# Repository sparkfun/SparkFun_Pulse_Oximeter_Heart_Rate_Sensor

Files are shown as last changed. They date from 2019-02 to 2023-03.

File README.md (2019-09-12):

SparkFun Pulse Oximeter and Heart Rate Monitor 
========================================

SparkFun Pulse Oximeter and Heart Rate Monitor

[*SparkFun Pulse Oximeter and Heart Rate Monitor (SEN-15291)*](https://www.sparkfun.com/products/15219)

The SparkFun Pulse Oximeter and Heart-Rate Sensor is an I&sup2;C based [biometric](https://en.wikipedia.org/wiki/Biometrics) sensor, utilizing two chips from Maxim Integrated: 
the MAX32664 Bio Metric Sensor Hub and the MAX30101 Pulse Oximetry and Heart-Rate Module.

The MAX30101 does all the sensing by utilizing its' internal LEDs to bounce light off the arteries and arterioles in your finger's subcutaneous layer and sensing how much light 
is absorbed with its' photodetectors . This is known as [photoplethysmography](https://en.wikipedia.org/wiki/Photoplethysmogram). This data is passed onto and analyzed by the 
MAX32664 which applies its' algorithms to determine heart rate and blood oxygen saturation (SpO2). The embedded algorithm uses digital filtering, pressure/position compensation, 
advanced R-wave detection and automatic gain control to determine the heart rate in beats per minute while minimizing power.  SpO2 results are reported as percentage of hemoglobin 
that is saturated with oxygen. It also provides useful information such as the sensor's confidence in its' reportings as well as a handy finger detection data point. To get the 
most out of the sensor we've written an Arduino Library to make it easy to adjust all the possible configurations.

Repository Contents
-------------------

* **/Documentation** - Data sheets and additional product information.
* **/Firmware** - Programming File for the MAX32664 
* **/Hardware** - Eagle design files (.brd, .sch)
* **/Production** - Production panel files (.brd)

Documentation
--------------
* **[Arduino Library](https://github.com/sparkfun/SparkFun_Bio_Sensor_Hub_Library)** - Arduino Library with Example Sketches
* **[Hookup Guide](https://learn.sparkfun.com/tutorials/sparkfun-pulse-oximeter-and-heart-rate-monitor-hookup-guide)** - Basic hookup guide for the SparkFun Pulse Oximeter and Heart Rate Sensor.

Product Versions
----------------
* [SEN-15291](https://www.sparkfun.com/products/15219)- SparkFun Version 1.0

License Information
-------------------

This product is _**open source**_! 

Please review the LICENSE.md file for license information. 

If you have any questions or concerns on licensing, please contact technical support on our [SparkFun forums](https://forum.sparkfun.com/viewforum.php?f=152).

Distributed as-is; no warranty is given.

- Your friends at SparkFun.

_<COLLABORATION CREDIT>_

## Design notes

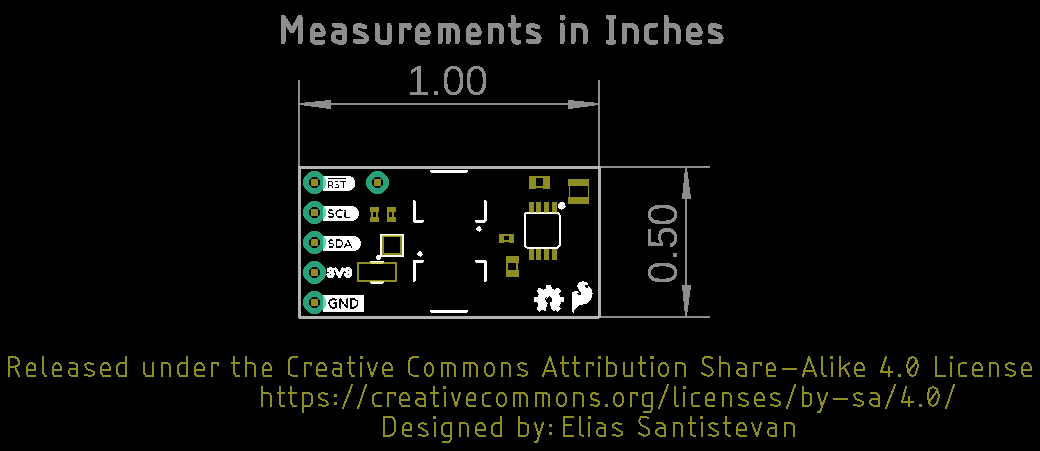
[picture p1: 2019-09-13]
Documentation/SparkFun_Pulse_Oximeter_Heart_Rate_Sensor_Dimensions.png

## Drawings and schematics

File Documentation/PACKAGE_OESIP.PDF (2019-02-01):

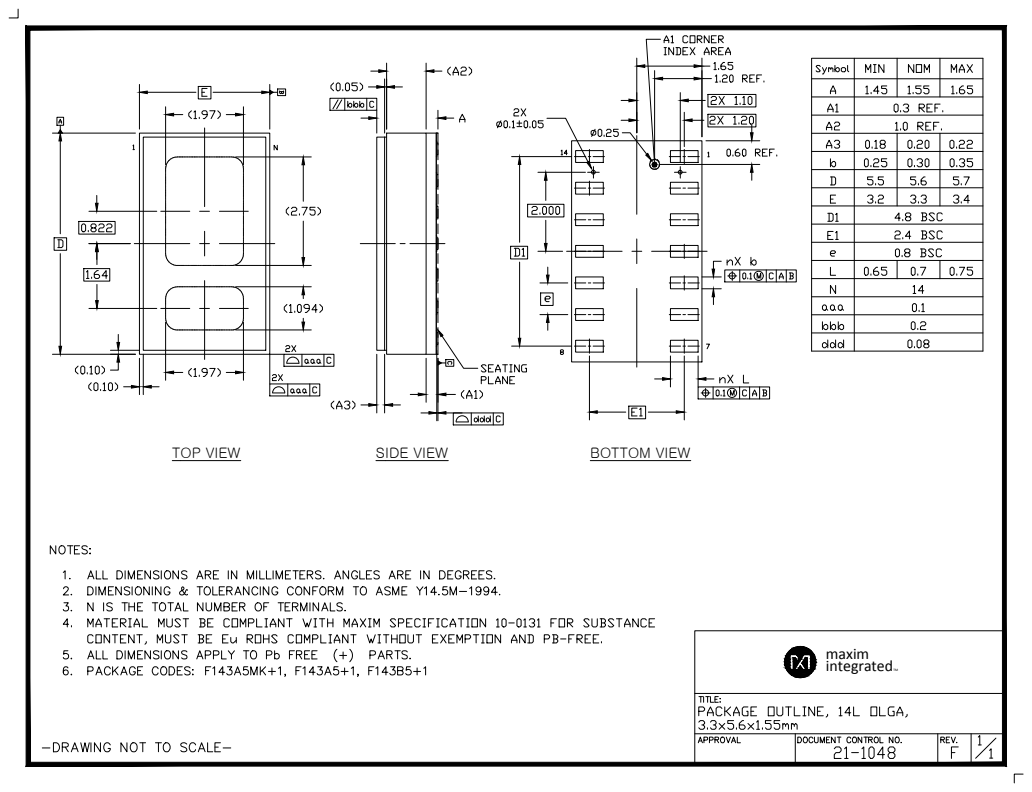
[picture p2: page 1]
maxim integratedTM TOP VIEW; SIDE VIEW; BOTTOM VIEW

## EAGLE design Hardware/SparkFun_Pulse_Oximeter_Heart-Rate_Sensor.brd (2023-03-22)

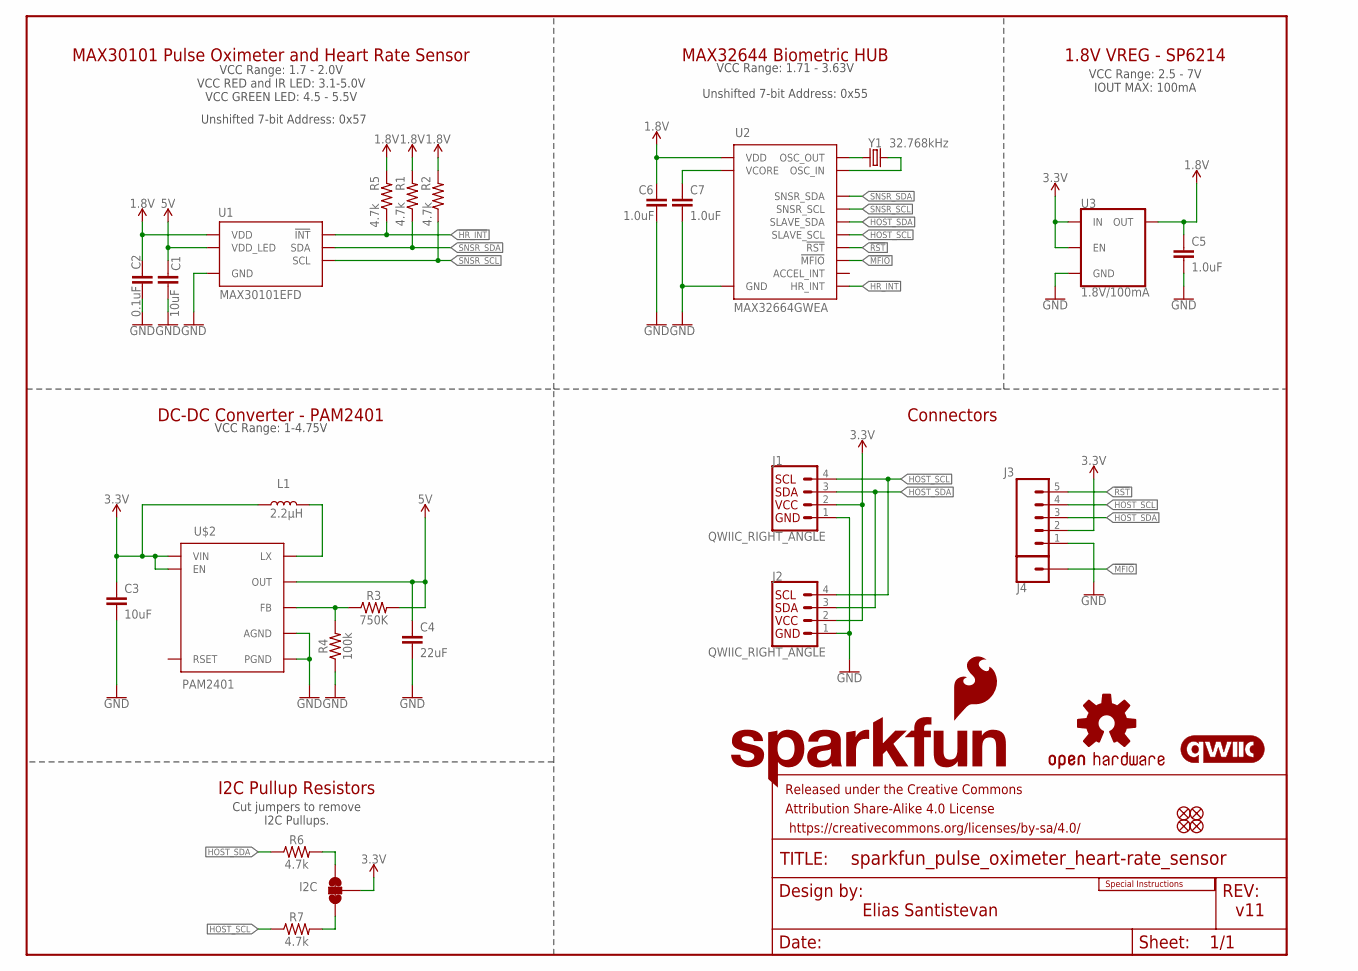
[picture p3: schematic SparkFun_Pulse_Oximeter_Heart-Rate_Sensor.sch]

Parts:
C1, C3: 10uF; 0603
C2: 0.1uF; 0402-TIGHT
C4: 22uF; 0805
C5: 1.0uF; 0603
C6, C7: 1.0uF; 0402-TIGHT
FD1, FD2, FD3, FD4: FIDUCIALUFIDUCIAL; FIDUCIAL-MICRO
FRAME1: FRAME-LETTER; CREATIVE_COMMONS
I2C: JUMPER-SMT_3_2-NC_TRACE_SILK; SMT-JUMPER_3_2-NC_TRACE_SILK
J1, J2: QWIIC_RIGHT_ANGLE; JST04_1MM_RA
J3: CONN_05NO_SILK; 1X05_NO_SILK
J4: CONN_01PTH_NO_SILK_YES_STOP; 1X01_NO_SILK
L1: 2.2μH; 0806
LOGO1: SFE_LOGO_FLAME.1_INCH; SFE_LOGO_FLAME_.1
LOGO2: OSHW-LOGOMINI; OSHW-LOGO-MINI
LOGO3: SFE_LOGO_NAME.1_INCH; SFE_LOGO_NAME_.1
LOGO4: SPECIAL_INSTRUCTIONS-ORDERING; ORDERING_INSTRUCTIONS
LOGO5: QWIIC_LOGO_4MM; QWIIC_4MM
R1, R2, R5, R6, R7: 4.7k; 0603
R3: 750K; 0603
R4: 100k; 0402-TIGHT
U1: MAX30101EFD; 14_PIN_OESIP
U2: MAX32664GWEA; 16_PIN_WLP
U3: 1.8V/100mA; SC70
U$2: PAM2401; MSOP8
Y1: 32.768kHz; CRYSTAL-SMD-3.2X1.5MM

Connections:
1.8V: C2.1, C5.1, C6.1, R1.2, R2.2, R5.2, U1.P11 (VDD), U2.3 (VDD), U3.5 (OUT)
3.3V: C3.1, I2C.2, J1.2, J2.2, J3.2, L1.1, U3.1 (IN), U3.3 (EN), U$2.2 (EN), U$2.3 (VIN)
5V: C1.1, C4.1, R3.2, U1.P9 (VDD_LED), U1.P10 (VDD_LED), U$2.7 (OUT)
!HR_INT: R5.1, U1.P13 (!INT), U2.6 (HR_INT)
!MFIO: J4.1, U2.16 (!MFIO)
!RST: J3.5, U2.12 (!RST)
GND: C1.2, C2.2, C3.2, C4.2, C5.2, C6.2, C7.2, J1.1, J2.1, J3.1, R4.1, U1.P4 (GND), U1.P12 (GND), U2.13 (GND), U3.2 (GND), U$2.4 (AGND), U$2.8 (PGND)
HOST_SCL: J1.4, J2.4, J3.4, R7.1, U2.10 (SLAVE_SCL)
HOST_SDA: J1.3, J2.3, J3.3, R6.1, U2.9 (SLAVE_SDA)
unnamed: C7.1, U2.4 (VCORE)
unnamed: R3.1, R4.2, U$2.5 (FB)
unnamed: L1.2, U$2.1 (LX)
unnamed: I2C.3, R6.2
unnamed: I2C.1, R7.2
unnamed: U2.1 (OSC_OUT), Y1.P$1 (1)
unnamed: U2.2 (OSC_IN), Y1.P$2 (2)
SNSR_SCL: R2.1, U1.P2 (SCL), U2.5 (SNSR_SCL)
SNSR_SDA: R1.1, U1.P3 (SDA), U2.14 (SNSR_SDA)

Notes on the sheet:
Elias Santistevan
v11
VCC Range: 1.71 - 3.63V
Unshifted 7-bit Address: 0x55
MAX30101 Pulse Oximeter and Heart Rate Sensor
MAX32644 Biometric HUB
1.8V VREG - SP6214
DC-DC Converter - PAM2401
Connectors
I2C Pullup Resistors
VCC Range: 1.7 - 2.0V VCC RED and IR LED: 3.1-5.0V VCC GREEN LED: 4.5 - 5.5V
Unshifted 7-bit Address: 0x57
VCC Range: 2.5 - 7V IOUT MAX: 100mA
VCC Range: 1-4.75V
Cut jumpers to remove I2C Pullups.

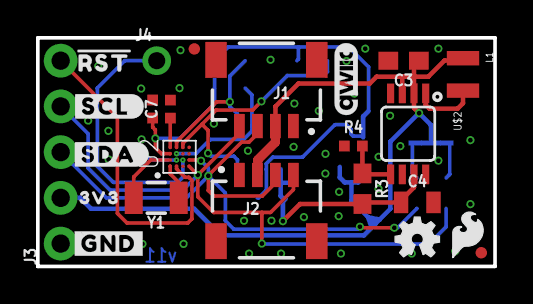
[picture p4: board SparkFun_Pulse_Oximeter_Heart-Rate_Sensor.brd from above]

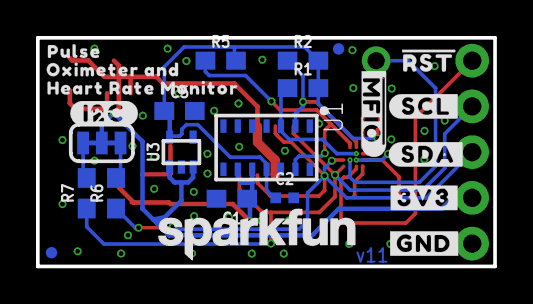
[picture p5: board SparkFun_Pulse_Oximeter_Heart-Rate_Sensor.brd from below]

Board: 2 copper layers, 25.4 x 12.7 mm, 50 parts (24 on the bottom side), 18 nets.

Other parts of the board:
U$1: #I2C#1348
U$3, U$5: #GND#0
U$4: #SCL#7
U$6, U$12: #RST#32
U$7: 3V338
U$8: #SDA#10
U$9: #3V3#1
U$10: #SDA#9
U$11: #SCL#9
U$13: ##MFIO##12
U$17: PULSE35
U$20: OXIMETER_AND36
U$21: HEART_RATE_MONITOR37

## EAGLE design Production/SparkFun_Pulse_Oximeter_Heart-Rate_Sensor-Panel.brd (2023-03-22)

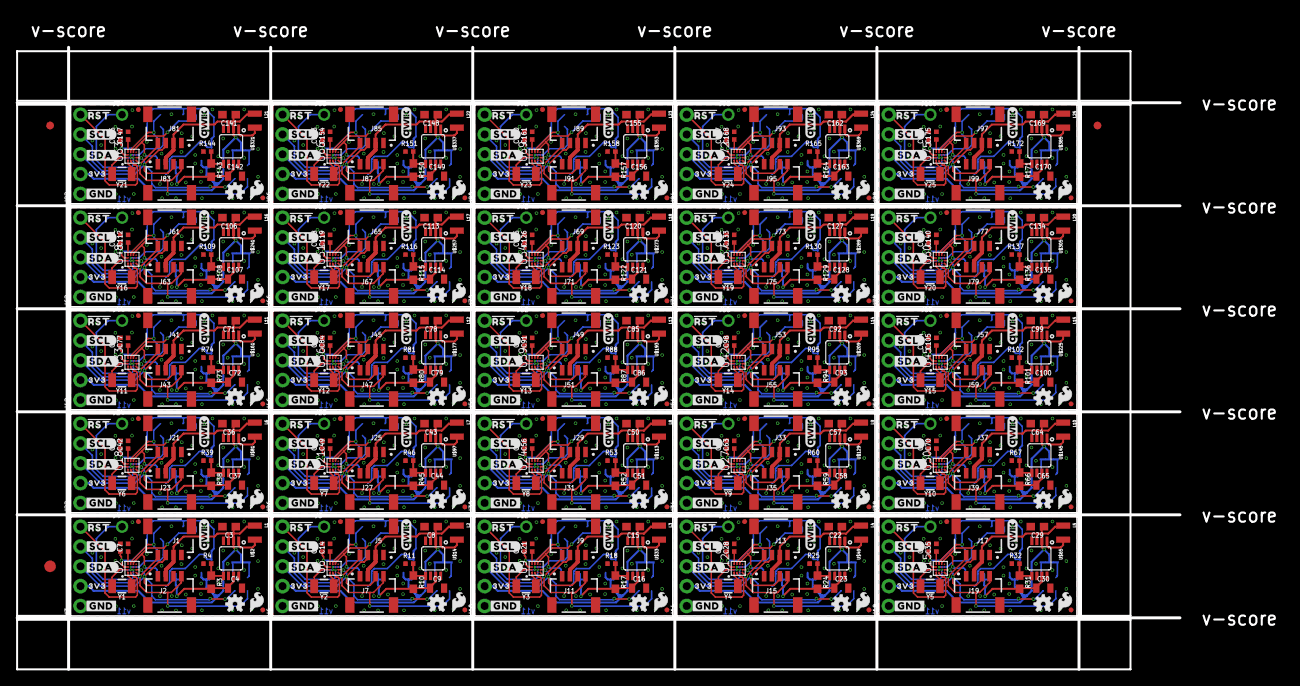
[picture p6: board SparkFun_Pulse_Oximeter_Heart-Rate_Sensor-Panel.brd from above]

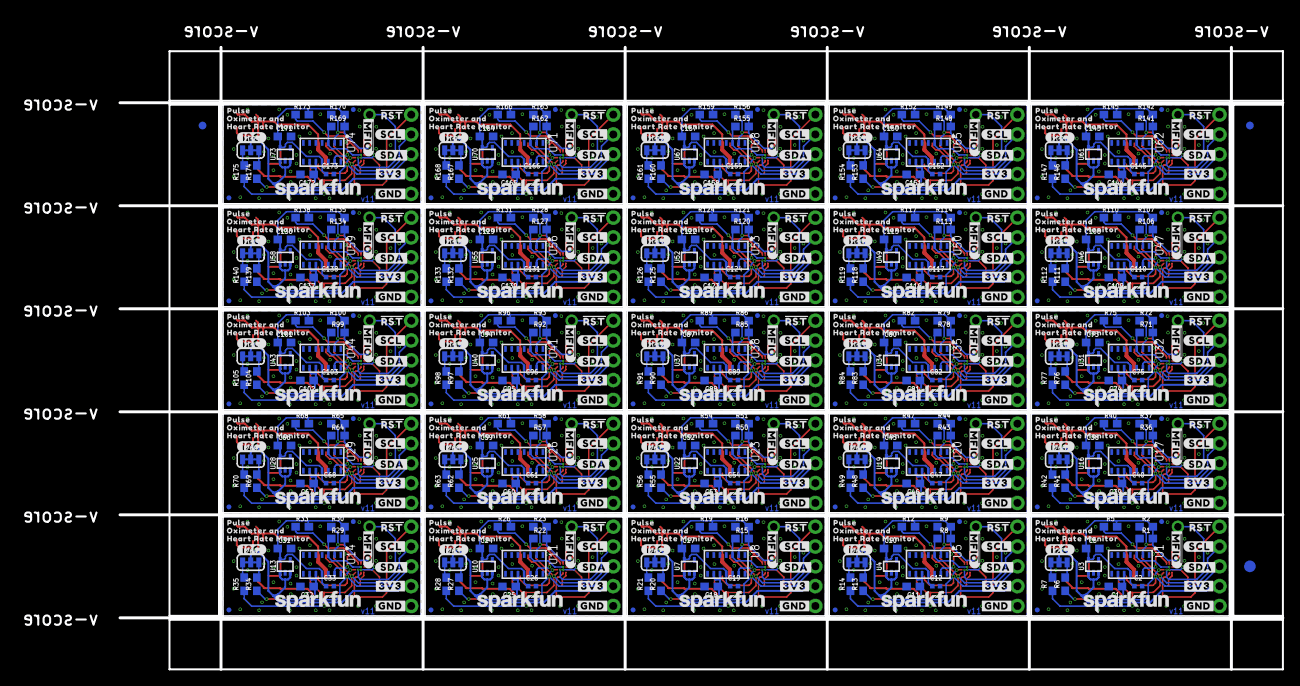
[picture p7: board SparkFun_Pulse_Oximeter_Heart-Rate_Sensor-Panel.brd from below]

Board: 2 copper layers, 149.1 x 79.8 mm, 1206 parts (603 on the bottom side), 450 nets.

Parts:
C1, C3, C8, C11, C15, C18, C22, C25, C29, C32, C36, C39, C43, C46, C50, C53, C57, C60, C64, C67, C71, C74, C78, C81, C85, C88, C92, C95, C99, C102, C106, C109, C113, C116, C120, C123, C127, C130, C134, C137, C141, C144, C148, C151, C155, C158, C162, C165, C169, C172: 10uF; 0603
C2, C12, C19, C26, C33, C40, C47, C54, C61, C68, C75, C82, C89, C96, C103, C110, C117, C124, C131, C138, C145, C152, C159, C166, C173: 0.1uF; 0402-TIGHT
C4, C9, C16, C23, C30, C37, C44, C51, C58, C65, C72, C79, C86, C93, C100, C107, C114, C121, C128, C135, C142, C149, C156, C163, C170: 22uF; 0805
C5, C10, C17, C24, C31, C38, C45, C52, C59, C66, C73, C80, C87, C94, C101, C108, C115, C122, C129, C136, C143, C150, C157, C164, C171: 1.0uF; 0603
C6, C7, C13, C14, C20, C21, C27, C28, C34, C35, C41, C42, C48, C49, C55, C56, C62, C63, C69, C70, C76, C77, C83, C84, C90, C91, C97, C98, C104, C105, C111, C112, C118, C119, C125, C126, C132, C133, C139, C140, C146, C147, C153, C154, C160, C161, C167, C168, C174, C175: 1.0uF; 0402-TIGHT
E$1, E$2, E$3, E$4: FIDUCIAL-1X2
E$5, E$6: FIDUCIAL-1.5X3
FD1, FD2, FD3, FD4, FD5, FD6, FD7, FD8, FD9, FD10, FD11, FD12, FD13, FD14, FD15, FD16, FD17, FD18, FD19, FD20, FD21, FD22, FD23, FD24, FD25, FD26, FD27, FD28, FD29, FD30, FD31, FD32, FD33, FD34, FD35, FD36, FD37, FD38, FD39, FD40, FD41, FD42, FD43, FD44, FD45, FD46, FD47, FD48, FD49, FD50, FD51, FD52, FD53, FD54, FD55, FD56, FD57, FD58, FD59, FD60, FD61, FD62, FD63, FD64, FD65, FD66, FD67, FD68, FD69, FD70, FD71, FD72, FD73, FD74, FD75, FD76, FD77, FD78, FD79, FD80, FD81, FD82, FD83, FD84, FD85, FD86, FD87, FD88, FD89, FD90, FD91, FD92, FD93, FD94, FD95, FD96, FD97, FD98, FD99, FD100: FIDUCIALUFIDUCIAL; FIDUCIAL-MICRO
I2C, I2C1, I2C2, I2C3, I2C4, I2C5, I2C6, I2C7, I2C8, I2C9, I2C10, I2C11, I2C12, I2C13, I2C14, I2C15, I2C16, I2C17, I2C18, I2C19, I2C20, I2C21, I2C22, I2C23, I2C24: JUMPER-SMT_3_2-NC_TRACE_SILK; SMT-JUMPER_3_2-NC_TRACE_SILK
J1, J2, J5, J7, J9, J11, J13, J15, J17, J19, J21, J23, J25, J27, J29, J31, J33, J35, J37, J39, J41, J43, J45, J47, J49, J51, J53, J55, J57, J59, J61, J63, J65, J67, J69, J71, J73, J75, J77, J79, J81, J83, J85, J87, J89, J91, J93, J95, J97, J99: QWIIC_RIGHT_ANGLE; JST04_1MM_RA
J3, J6, J10, J14, J18, J22, J26, J30, J34, J38, J42, J46, J50, J54, J58, J62, J66, J70, J74, J78, J82, J86, J90, J94, J98: 1X05_NO_SILK
J4, J8, J12, J16, J20, J24, J28, J32, J36, J40, J44, J48, J52, J56, J60, J64, J68, J72, J76, J80, J84, J88, J92, J96, J100: 1X01_NO_SILK
L1, L2, L3, L4, L5, L6, L7, L8, L9, L10, L11, L12, L13, L14, L15, L16, L17, L18, L19, L20, L21, L22, L23, L24, L25: 2.2μH; 0806
LOGO1, LOGO4, LOGO9, LOGO13, LOGO17, LOGO21, LOGO25, LOGO29, LOGO33, LOGO37, LOGO41, LOGO45, LOGO49, LOGO53, LOGO57, LOGO61, LOGO65, LOGO69, LOGO73, LOGO77, LOGO81, LOGO85, LOGO89, LOGO93, LOGO97: SFE_LOGO_FLAME.1_INCH; SFE_LOGO_FLAME_.1
LOGO2, LOGO6, LOGO10, LOGO14, LOGO18, LOGO22, LOGO26, LOGO30, LOGO34, LOGO38, LOGO42, LOGO46, LOGO50, LOGO54, LOGO58, LOGO62, LOGO66, LOGO70, LOGO74, LOGO78, LOGO82, LOGO86, LOGO90, LOGO94, LOGO98: OSHW-LOGOMINI; OSHW-LOGO-MINI
LOGO3, LOGO7, LOGO11, LOGO15, LOGO19, LOGO23, LOGO27, LOGO31, LOGO35, LOGO39, LOGO43, LOGO47, LOGO51, LOGO55, LOGO59, LOGO63, LOGO67, LOGO71, LOGO75, LOGO79, LOGO83, LOGO87, LOGO91, LOGO95, LOGO99: SFE_LOGO_NAME.1_INCH; SFE_LOGO_NAME_.1
LOGO5, LOGO8, LOGO12, LOGO16, LOGO20, LOGO24, LOGO28, LOGO32, LOGO36, LOGO40, LOGO44, LOGO48, LOGO52, LOGO56, LOGO60, LOGO64, LOGO68, LOGO72, LOGO76, LOGO80, LOGO84, LOGO88, LOGO92, LOGO96, LOGO100: QWIIC_LOGO_4MM; QWIIC_4MM
R1, R2, R5, R6, R7, R8, R9, R12, R13, R14, R15, R16, R19, R20, R21, R22, R23, R26, R27, R28, R29, R30, R33, R34, R35, R36, R37, R40, R41, R42, R43, R44, R47, R48, R49, R50, R51, R54, R55, R56, R57, R58, R61, R62, R63, R64, R65, R68, R69, R70, R71, R72, R75, R76, R77, R78, R79, R82, R83, R84, R85, R86, R89, R90, R91, R92, R93, R96, R97, R98, R99, R100, R103, R104, R105, R106, R107, R110, R111, R112, R113, R114, R117, R118, R119, R120, R121, R124, R125, R126, R127, R128, R131, R132, R133, R134, R135, R138, R139, R140, R141, R142, R145, R146, R147, R148, R149, R152, R153, R154, R155, R156, R159, R160, R161, R162, R163, R166, R167, R168, R169, R170, R173, R174, R175: 4.7k; 0603
R3, R10, R17, R24, R31, R38, R45, R52, R59, R66, R73, R80, R87, R94, R101, R108, R115, R122, R129, R136, R143, R150, R157, R164, R171: 750K; 0603
R4, R11, R18, R25, R32, R39, R46, R53, R60, R67, R74, R81, R88, R95, R102, R109, R116, R123, R130, R137, R144, R151, R158, R165, R172: 100k; 0402-TIGHT
U1, U5, U8, U11, U14, U17, U20, U23, U26, U29, U32, U35, U38, U41, U44, U47, U50, U53, U56, U59, U62, U65, U68, U71, U74: MAX30101EFD; 14_PIN_OESIP
U2, U6, U9, U12, U15, U18, U21, U24, U27, U30, U33, U36, U39, U42, U45, U48, U51, U54, U57, U60, U63, U66, U69, U72, U75: MAX32664GWEA; 16_PIN_WLP
U3, U4, U7, U10, U13, U16, U19, U22, U25, U28, U31, U34, U37, U40, U43, U46, U49, U52, U55, U58, U61, U64, U67, U70, U73: 1.8V/100mA; SC70
U$1, U$27, U$43, U$59, U$75, U$91, U$107, U$123, U$139, U$155, U$171, U$187, U$203, U$219, U$235, U$251, U$267, U$283, U$299, U$315, U$331, U$347, U$363, U$379, U$395: #I2C#1348
U$2, U$14, U$33, U$49, U$65, U$81, U$97, U$113, U$129, U$145, U$161, U$177, U$193, U$209, U$225, U$241, U$257, U$273, U$289, U$305, U$321, U$337, U$353, U$369, U$385: PAM2401; MSOP8
U$3, U$5, U$19, U$22, U$37, U$38, U$53, U$54, U$69, U$70, U$85, U$86, U$101, U$102, U$117, U$118, U$133, U$134, U$149, U$150, U$165, U$166, U$181, U$182, U$197, U$198, U$213, U$214, U$229, U$230, U$245, U$246, U$261, U$262, U$277, U$278, U$293, U$294, U$309, U$310, U$325, U$326, U$341, U$342, U$357, U$358, U$373, U$374, U$389, U$390: #GND#0
U$4, U$16, U$35, U$51, U$67, U$83, U$99, U$115, U$131, U$147, U$163, U$179, U$195, U$211, U$227, U$243, U$259, U$275, U$291, U$307, U$323, U$339, U$355, U$371, U$387: #SCL#7
U$6, U$12, U$15, U$26, U$34, U$42, U$50, U$58, U$66, U$74, U$82, U$90, U$98, U$106, U$114, U$122, U$130, U$138, U$146, U$154, U$162, U$170, U$178, U$186, U$194, U$202, U$210, U$218, U$226, U$234, U$242, U$250, U$258, U$266, U$274, U$282, U$290, U$298, U$306, U$314, U$322, U$330, U$338, U$346, U$354, U$362, U$370, U$378, U$386, U$394: #RST#32
U$7, U$28, U$44, U$60, U$76, U$92, U$108, U$124, U$140, U$156, U$172, U$188, U$204, U$220, U$236, U$252, U$268, U$284, U$300, U$316, U$332, U$348, U$364, U$380, U$396: 3V338
U$8, U$18, U$36, U$52, U$68, U$84, U$100, U$116, U$132, U$148, U$164, U$180, U$196, U$212, U$228, U$244, U$260, U$276, U$292, U$308, U$324, U$340, U$356, U$372, U$388: #SDA#10
U$9, U$23, U$39, U$55, U$71, U$87, U$103, U$119, U$135, U$151, U$167, U$183, U$199, U$215, U$231, U$247, U$263, U$279, U$295, U$311, U$327, U$343, U$359, U$375, U$391: #3V3#1
U$10, U$24, U$40, U$56, U$72, U$88, U$104, U$120, U$136, U$152, U$168, U$184, U$200, U$216, U$232, U$248, U$264, U$280, U$296, U$312, U$328, U$344, U$360, U$376, U$392: #SDA#9
U$11, U$25, U$41, U$57, U$73, U$89, U$105, U$121, U$137, U$153, U$169, U$185, U$201, U$217, U$233, U$249, U$265, U$281, U$297, U$313, U$329, U$345, U$361, U$377, U$393: #SCL#9
U$13, U$29, U$45, U$61, U$77, U$93, U$109, U$125, U$141, U$157, U$173, U$189, U$205, U$221, U$237, U$253, U$269, U$285, U$301, U$317, U$333, U$349, U$365, U$381, U$397: ##MFIO##12
U$17, U$30, U$46, U$62, U$78, U$94, U$110, U$126, U$142, U$158, U$174, U$190, U$206, U$222, U$238, U$254, U$270, U$286, U$302, U$318, U$334, U$350, U$366, U$382, U$398: PULSE35
U$20, U$31, U$47, U$63, U$79, U$95, U$111, U$127, U$143, U$159, U$175, U$191, U$207, U$223, U$239, U$255, U$271, U$287, U$303, U$319, U$335, U$351, U$367, U$383, U$399: OXIMETER_AND36
U$21, U$32, U$48, U$64, U$80, U$96, U$112, U$128, U$144, U$160, U$176, U$192, U$208, U$224, U$240, U$256, U$272, U$288, U$304, U$320, U$336, U$352, U$368, U$384, U$400: HEART_RATE_MONITOR37
Y1, Y2, Y3, Y4, Y5, Y6, Y7, Y8, Y9, Y10, Y11, Y12, Y13, Y14, Y15, Y16, Y17, Y18, Y19, Y20, Y21, Y22, Y23, Y24, Y25: 32.768kHz; CRYSTAL-SMD-3.2X1.5MM

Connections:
1.8V: C2.1, C5.1, C6.1, R1.2, R2.2, R5.2, U1.P11, U2.3, U3.5
1.8V1: C10.1, C12.1, C13.1, R8.2, R9.2, R12.2, U4.5, U5.P11, U6.3
1.8V2: C17.1, C19.1, C20.1, R15.2, R16.2, R19.2, U7.5, U8.P11, U9.3
1.8V3: C24.1, C26.1, C27.1, R22.2, R23.2, R26.2, U10.5, U11.P11, U12.3
1.8V4: C31.1, C33.1, C34.1, R29.2, R30.2, R33.2, U13.5, U14.P11, U15.3
1.8V5: C38.1, C40.1, C41.1, R36.2, R37.2, R40.2, U16.5, U17.P11, U18.3
1.8V6: C45.1, C47.1, C48.1, R43.2, R44.2, R47.2, U19.5, U20.P11, U21.3
1.8V7: C52.1, C54.1, C55.1, R50.2, R51.2, R54.2, U22.5, U23.P11, U24.3
1.8V8: C59.1, C61.1, C62.1, R57.2, R58.2, R61.2, U25.5, U26.P11, U27.3
1.8V9: C66.1, C68.1, C69.1, R64.2, R65.2, R68.2, U28.5, U29.P11, U30.3
1.8V10: C73.1, C75.1, C76.1, R71.2, R72.2, R75.2, U31.5, U32.P11, U33.3
1.8V11: C80.1, C82.1, C83.1, R78.2, R79.2, R82.2, U34.5, U35.P11, U36.3
1.8V12: C87.1, C89.1, C90.1, R85.2, R86.2, R89.2, U37.5, U38.P11, U39.3
1.8V13: C94.1, C96.1, C97.1, R92.2, R93.2, R96.2, U40.5, U41.P11, U42.3
1.8V14: C101.1, C103.1, C104.1, R99.2, R100.2, R103.2, U43.5, U44.P11, U45.3
1.8V15: C108.1, C110.1, C111.1, R106.2, R107.2, R110.2, U46.5, U47.P11, U48.3
1.8V16: C115.1, C117.1, C118.1, R113.2, R114.2, R117.2, U49.5, U50.P11, U51.3
1.8V17: C122.1, C124.1, C125.1, R120.2, R121.2, R124.2, U52.5, U53.P11, U54.3
1.8V18: C129.1, C131.1, C132.1, R127.2, R128.2, R131.2, U55.5, U56.P11, U57.3
1.8V19: C136.1, C138.1, C139.1, R134.2, R135.2, R138.2, U58.5, U59.P11, U60.3
1.8V20: C143.1, C145.1, C146.1, R141.2, R142.2, R145.2, U61.5, U62.P11, U63.3
1.8V21: C150.1, C152.1, C153.1, R148.2, R149.2, R152.2, U64.5, U65.P11, U66.3
1.8V22: C157.1, C159.1, C160.1, R155.2, R156.2, R159.2, U67.5, U68.P11, U69.3
1.8V23: C164.1, C166.1, C167.1, R162.2, R163.2, R166.2, U70.5, U71.P11, U72.3
1.8V24: C171.1, C173.1, C174.1, R169.2, R170.2, R173.2, U73.5, U74.P11, U75.3
3.3V: C3.1, I2C.2, J1.2, J2.2, J3.2, L1.1, U3.1, U3.3, U$2.2, U$2.3
3.3V1: C8.1, I2C1.2, J5.2, J6.2, J7.2, L2.1, U4.1, U4.3, U$14.2, U$14.3
3.3V2: C15.1, I2C2.2, J9.2, J10.2, J11.2, L3.1, U7.1, U7.3, U$33.2, U$33.3
3.3V3: C22.1, I2C3.2, J13.2, J14.2, J15.2, L4.1, U10.1, U10.3, U$49.2, U$49.3
3.3V4: C29.1, I2C4.2, J17.2, J18.2, J19.2, L5.1, U13.1, U13.3, U$65.2, U$65.3
3.3V5: C36.1, I2C5.2, J21.2, J22.2, J23.2, L6.1, U16.1, U16.3, U$81.2, U$81.3
3.3V6: C43.1, I2C6.2, J25.2, J26.2, J27.2, L7.1, U19.1, U19.3, U$97.2, U$97.3
3.3V7: C50.1, I2C7.2, J29.2, J30.2, J31.2, L8.1, U22.1, U22.3, U$113.2, U$113.3
3.3V8: C57.1, I2C8.2, J33.2, J34.2, J35.2, L9.1, U25.1, U25.3, U$129.2, U$129.3
3.3V9: C64.1, I2C9.2, J37.2, J38.2, J39.2, L10.1, U28.1, U28.3, U$145.2, U$145.3
3.3V10: C71.1, I2C10.2, J41.2, J42.2, J43.2, L11.1, U31.1, U31.3, U$161.2, U$161.3
3.3V11: C78.1, I2C11.2, J45.2, J46.2, J47.2, L12.1, U34.1, U34.3, U$177.2, U$177.3
3.3V12: C85.1, I2C12.2, J49.2, J50.2, J51.2, L13.1, U37.1, U37.3, U$193.2, U$193.3
3.3V13: C92.1, I2C13.2, J53.2, J54.2, J55.2, L14.1, U40.1, U40.3, U$209.2, U$209.3
3.3V14: C99.1, I2C14.2, J57.2, J58.2, J59.2, L15.1, U43.1, U43.3, U$225.2, U$225.3
3.3V15: C106.1, I2C15.2, J61.2, J62.2, J63.2, L16.1, U46.1, U46.3, U$241.2, U$241.3
3.3V16: C113.1, I2C16.2, J65.2, J66.2, J67.2, L17.1, U49.1, U49.3, U$257.2, U$257.3
3.3V17: C120.1, I2C17.2, J69.2, J70.2, J71.2, L18.1, U52.1, U52.3, U$273.2, U$273.3
3.3V18: C127.1, I2C18.2, J73.2, J74.2, J75.2, L19.1, U55.1, U55.3, U$289.2, U$289.3
3.3V19: C134.1, I2C19.2, J77.2, J78.2, J79.2, L20.1, U58.1, U58.3, U$305.2, U$305.3
3.3V20: C141.1, I2C20.2, J81.2, J82.2, J83.2, L21.1, U61.1, U61.3, U$321.2, U$321.3
3.3V21: C148.1, I2C21.2, J85.2, J86.2, J87.2, L22.1, U64.1, U64.3, U$337.2, U$337.3
3.3V22: C155.1, I2C22.2, J89.2, J90.2, J91.2, L23.1, U67.1, U67.3, U$353.2, U$353.3
3.3V23: C162.1, I2C23.2, J93.2, J94.2, J95.2, L24.1, U70.1, U70.3, U$369.2, U$369.3
3.3V24: C169.1, I2C24.2, J97.2, J98.2, J99.2, L25.1, U73.1, U73.3, U$385.2, U$385.3
5V: C1.1, C4.1, R3.2, U1.P9, U1.P10, U$2.7
5V1: C9.1, C11.1, R10.2, U5.P9, U5.P10, U$14.7
5V2: C16.1, C18.1, R17.2, U8.P9, U8.P10, U$33.7
5V3: C23.1, C25.1, R24.2, U11.P9, U11.P10, U$49.7
5V4: C30.1, C32.1, R31.2, U14.P9, U14.P10, U$65.7
5V5: C37.1, C39.1, R38.2, U17.P9, U17.P10, U$81.7
5V6: C44.1, C46.1, R45.2, U20.P9, U20.P10, U$97.7
5V7: C51.1, C53.1, R52.2, U23.P9, U23.P10, U$113.7
5V8: C58.1, C60.1, R59.2, U26.P9, U26.P10, U$129.7
5V9: C65.1, C67.1, R66.2, U29.P9, U29.P10, U$145.7
5V10: C72.1, C74.1, R73.2, U32.P9, U32.P10, U$161.7
5V11: C79.1, C81.1, R80.2, U35.P9, U35.P10, U$177.7
5V12: C86.1, C88.1, R87.2, U38.P9, U38.P10, U$193.7
5V13: C93.1, C95.1, R94.2, U41.P9, U41.P10, U$209.7
5V14: C100.1, C102.1, R101.2, U44.P9, U44.P10, U$225.7
5V15: C107.1, C109.1, R108.2, U47.P9, U47.P10, U$241.7
5V16: C114.1, C116.1, R115.2, U50.P9, U50.P10, U$257.7
5V17: C121.1, C123.1, R122.2, U53.P9, U53.P10, U$273.7
5V18: C128.1, C130.1, R129.2, U56.P9, U56.P10, U$289.7
5V19: C135.1, C137.1, R136.2, U59.P9, U59.P10, U$305.7
5V20: C142.1, C144.1, R143.2, U62.P9, U62.P10, U$321.7
5V21: C149.1, C151.1, R150.2, U65.P9, U65.P10, U$337.7
5V22: C156.1, C158.1, R157.2, U68.P9, U68.P10, U$353.7
5V23: C163.1, C165.1, R164.2, U71.P9, U71.P10, U$369.7
5V24: C170.1, C172.1, R171.2, U74.P9, U74.P10, U$385.7
!HR_INT: R5.1, U1.P13, U2.6
!HR_INT1: R12.1, U5.P13, U6.6
!HR_INT2: R19.1, U8.P13, U9.6
!HR_INT3: R26.1, U11.P13, U12.6
!HR_INT4: R33.1, U14.P13, U15.6
!HR_INT5: R40.1, U17.P13, U18.6
!HR_INT6: R47.1, U20.P13, U21.6
!HR_INT7: R54.1, U23.P13, U24.6
!HR_INT8: R61.1, U26.P13, U27.6
!HR_INT9: R68.1, U29.P13, U30.6
!HR_INT10: R75.1, U32.P13, U33.6
!HR_INT11: R82.1, U35.P13, U36.6
!HR_INT12: R89.1, U38.P13, U39.6
!HR_INT13: R96.1, U41.P13, U42.6
!HR_INT14: R103.1, U44.P13, U45.6
!HR_INT15: R110.1, U47.P13, U48.6
!HR_INT16: R117.1, U50.P13, U51.6
!HR_INT17: R124.1, U53.P13, U54.6
!HR_INT18: R131.1, U56.P13, U57.6
!HR_INT19: R138.1, U59.P13, U60.6
!HR_INT20: R145.1, U62.P13, U63.6
!HR_INT21: R152.1, U65.P13, U66.6
!HR_INT22: R159.1, U68.P13, U69.6
!HR_INT23: R166.1, U71.P13, U72.6
!HR_INT24: R173.1, U74.P13, U75.6
!MFIO: J4.1, U2.16
!MFIO1: J8.1, U6.16
!MFIO2: J12.1, U9.16
!MFIO3: J16.1, U12.16
!MFIO4: J20.1, U15.16
!MFIO5: J24.1, U18.16
!MFIO6: J28.1, U21.16
!MFIO7: J32.1, U24.16
!MFIO8: J36.1, U27.16
!MFIO9: J40.1, U30.16
!MFIO10: J44.1, U33.16
!MFIO11: J48.1, U36.16
!MFIO12: J52.1, U39.16
!MFIO13: J56.1, U42.16
!MFIO14: J60.1, U45.16
!MFIO15: J64.1, U48.16
!MFIO16: J68.1, U51.16
!MFIO17: J72.1, U54.16
!MFIO18: J76.1, U57.16
!MFIO19: J80.1, U60.16
!MFIO20: J84.1, U63.16
!MFIO21: J88.1, U66.16
!MFIO22: J92.1, U69.16
!MFIO23: J96.1, U72.16
!MFIO24: J100.1, U75.16
!RST: J3.5, U2.12
!RST1: J6.5, U6.12
!RST2: J10.5, U9.12
!RST3: J14.5, U12.12
!RST4: J18.5, U15.12
!RST5: J22.5, U18.12
!RST6: J26.5, U21.12
!RST7: J30.5, U24.12
!RST8: J34.5, U27.12
!RST9: J38.5, U30.12
!RST10: J42.5, U33.12
!RST11: J46.5, U36.12
!RST12: J50.5, U39.12
!RST13: J54.5, U42.12
!RST14: J58.5, U45.12
!RST15: J62.5, U48.12
!RST16: J66.5, U51.12
!RST17: J70.5, U54.12
!RST18: J74.5, U57.12
!RST19: J78.5, U60.12
!RST20: J82.5, U63.12
!RST21: J86.5, U66.12
!RST22: J90.5, U69.12
!RST23: J94.5, U72.12
!RST24: J98.5, U75.12
GND: C1.2, C2.2, C3.2, C4.2, C5.2, C6.2, C7.2, J1.1, J2.1, J3.1, R4.1, U1.P4, U1.P12, U2.13, U3.2, U$2.4, U$2.8
GND1: C8.2, C9.2, C10.2, C11.2, C12.2, C13.2, C14.2, J5.1, J6.1, J7.1, R11.1, U4.2, U5.P4, U5.P12, U6.13, U$14.4, U$14.8
GND2: C15.2, C16.2, C17.2, C18.2, C19.2, C20.2, C21.2, J9.1, J10.1, J11.1, R18.1, U7.2, U8.P4, U8.P12, U9.13, U$33.4, U$33.8
GND3: C22.2, C23.2, C24.2, C25.2, C26.2, C27.2, C28.2, J13.1, J14.1, J15.1, R25.1, U10.2, U11.P4, U11.P12, U12.13, U$49.4, U$49.8
GND4: C29.2, C30.2, C31.2, C32.2, C33.2, C34.2, C35.2, J17.1, J18.1, J19.1, R32.1, U13.2, U14.P4, U14.P12, U15.13, U$65.4, U$65.8
GND5: C36.2, C37.2, C38.2, C39.2, C40.2, C41.2, C42.2, J21.1, J22.1, J23.1, R39.1, U16.2, U17.P4, U17.P12, U18.13, U$81.4, U$81.8
GND6: C43.2, C44.2, C45.2, C46.2, C47.2, C48.2, C49.2, J25.1, J26.1, J27.1, R46.1, U19.2, U20.P4, U20.P12, U21.13, U$97.4, U$97.8
GND7: C50.2, C51.2, C52.2, C53.2, C54.2, C55.2, C56.2, J29.1, J30.1, J31.1, R53.1, U22.2, U23.P4, U23.P12, U24.13, U$113.4, U$113.8
GND8: C57.2, C58.2, C59.2, C60.2, C61.2, C62.2, C63.2, J33.1, J34.1, J35.1, R60.1, U25.2, U26.P4, U26.P12, U27.13, U$129.4, U$129.8
GND9: C64.2, C65.2, C66.2, C67.2, C68.2, C69.2, C70.2, J37.1, J38.1, J39.1, R67.1, U28.2, U29.P4, U29.P12, U30.13, U$145.4, U$145.8
GND10: C71.2, C72.2, C73.2, C74.2, C75.2, C76.2, C77.2, J41.1, J42.1, J43.1, R74.1, U31.2, U32.P4, U32.P12, U33.13, U$161.4, U$161.8
GND11: C78.2, C79.2, C80.2, C81.2, C82.2, C83.2, C84.2, J45.1, J46.1, J47.1, R81.1, U34.2, U35.P4, U35.P12, U36.13, U$177.4, U$177.8
GND12: C85.2, C86.2, C87.2, C88.2, C89.2, C90.2, C91.2, J49.1, J50.1, J51.1, R88.1, U37.2, U38.P4, U38.P12, U39.13, U$193.4, U$193.8
GND13: C92.2, C93.2, C94.2, C95.2, C96.2, C97.2, C98.2, J53.1, J54.1, J55.1, R95.1, U40.2, U41.P4, U41.P12, U42.13, U$209.4, U$209.8
GND14: C99.2, C100.2, C101.2, C102.2, C103.2, C104.2, C105.2, J57.1, J58.1, J59.1, R102.1, U43.2, U44.P4, U44.P12, U45.13, U$225.4, U$225.8
GND15: C106.2, C107.2, C108.2, C109.2, C110.2, C111.2, C112.2, J61.1, J62.1, J63.1, R109.1, U46.2, U47.P4, U47.P12, U48.13, U$241.4, U$241.8
GND16: C113.2, C114.2, C115.2, C116.2, C117.2, C118.2, C119.2, J65.1, J66.1, J67.1, R116.1, U49.2, U50.P4, U50.P12, U51.13, U$257.4, U$257.8
GND17: C120.2, C121.2, C122.2, C123.2, C124.2, C125.2, C126.2, J69.1, J70.1, J71.1, R123.1, U52.2, U53.P4, U53.P12, U54.13, U$273.4, U$273.8
GND18: C127.2, C128.2, C129.2, C130.2, C131.2, C132.2, C133.2, J73.1, J74.1, J75.1, R130.1, U55.2, U56.P4, U56.P12, U57.13, U$289.4, U$289.8
GND19: C134.2, C135.2, C136.2, C137.2, C138.2, C139.2, C140.2, J77.1, J78.1, J79.1, R137.1, U58.2, U59.P4, U59.P12, U60.13, U$305.4, U$305.8
GND20: C141.2, C142.2, C143.2, C144.2, C145.2, C146.2, C147.2, J81.1, J82.1, J83.1, R144.1, U61.2, U62.P4, U62.P12, U63.13, U$321.4, U$321.8
GND21: C148.2, C149.2, C150.2, C151.2, C152.2, C153.2, C154.2, J85.1, J86.1, J87.1, R151.1, U64.2, U65.P4, U65.P12, U66.13, U$337.4, U$337.8
GND22: C155.2, C156.2, C157.2, C158.2, C159.2, C160.2, C161.2, J89.1, J90.1, J91.1, R158.1, U67.2, U68.P4, U68.P12, U69.13, U$353.4, U$353.8
GND23: C162.2, C163.2, C164.2, C165.2, C166.2, C167.2, C168.2, J93.1, J94.1, J95.1, R165.1, U70.2, U71.P4, U71.P12, U72.13, U$369.4, U$369.8
GND24: C169.2, C170.2, C171.2, C172.2, C173.2, C174.2, C175.2, J97.1, J98.1, J99.1, R172.1, U73.2, U74.P4, U74.P12, U75.13, U$385.4, U$385.8
HOST_SCL: J1.4, J2.4, J3.4, R7.1, U2.10
HOST_SCL1: J5.4, J6.4, J7.4, R14.1, U6.10
HOST_SCL2: J9.4, J10.4, J11.4, R21.1, U9.10
HOST_SCL3: J13.4, J14.4, J15.4, R28.1, U12.10
HOST_SCL4: J17.4, J18.4, J19.4, R35.1, U15.10
HOST_SCL5: J21.4, J22.4, J23.4, R42.1, U18.10
HOST_SCL6: J25.4, J26.4, J27.4, R49.1, U21.10
HOST_SCL7: J29.4, J30.4, J31.4, R56.1, U24.10
HOST_SCL8: J33.4, J34.4, J35.4, R63.1, U27.10
HOST_SCL9: J37.4, J38.4, J39.4, R70.1, U30.10
HOST_SCL10: J41.4, J42.4, J43.4, R77.1, U33.10
HOST_SCL11: J45.4, J46.4, J47.4, R84.1, U36.10
HOST_SCL12: J49.4, J50.4, J51.4, R91.1, U39.10
HOST_SCL13: J53.4, J54.4, J55.4, R98.1, U42.10
HOST_SCL14: J57.4, J58.4, J59.4, R105.1, U45.10
HOST_SCL15: J61.4, J62.4, J63.4, R112.1, U48.10
HOST_SCL16: J65.4, J66.4, J67.4, R119.1, U51.10
HOST_SCL17: J69.4, J70.4, J71.4, R126.1, U54.10
HOST_SCL18: J73.4, J74.4, J75.4, R133.1, U57.10
HOST_SCL19: J77.4, J78.4, J79.4, R140.1, U60.10
HOST_SCL20: J81.4, J82.4, J83.4, R147.1, U63.10
HOST_SCL21: J85.4, J86.4, J87.4, R154.1, U66.10
HOST_SCL22: J89.4, J90.4, J91.4, R161.1, U69.10
HOST_SCL23: J93.4, J94.4, J95.4, R168.1, U72.10
HOST_SCL24: J97.4, J98.4, J99.4, R175.1, U75.10
HOST_SDA: J1.3, J2.3, J3.3, R6.1, U2.9
HOST_SDA1: J5.3, J6.3, J7.3, R13.1, U6.9
HOST_SDA2: J9.3, J10.3, J11.3, R20.1, U9.9
HOST_SDA3: J13.3, J14.3, J15.3, R27.1, U12.9
HOST_SDA4: J17.3, J18.3, J19.3, R34.1, U15.9
HOST_SDA5: J21.3, J22.3, J23.3, R41.1, U18.9
HOST_SDA6: J25.3, J26.3, J27.3, R48.1, U21.9
HOST_SDA7: J29.3, J30.3, J31.3, R55.1, U24.9
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

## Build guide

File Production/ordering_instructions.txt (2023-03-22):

panel size, 143x80mm
PCB thickness, 1.6mm
number of layers, 2
soldermask color, Red
silkscreen color, White
oz copper, 1oz
finish, HASL lead free
stencils, top+bottom
pcs per panel, 25
min trace width, 0.2032mm / 0.0080in
min drill size, 0.1016mm / 0.0040in

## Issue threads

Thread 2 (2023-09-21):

How to use BPT Estimation code?

Nimesh-Patel, 2023-09-21:
## Subject: How to use BPT Estimation code?
Hi,
I am trying to use SparkFun Pulse Oximeter and Heart Rate Sensor - MAX30101 & MAX32664 (Qwiic) and measure BPT Estimation.
The SparkFun_Bio_Sensor_Hub_Library.cpp file (line 1172 and onwards) suggests the function to measure BPT.
// ------------------Function Below for MAX32664 Version D (Blood Pressure) ----

The example code shows the heartrate measurement: How do I request to measure the BPT estimates and display Systolic and Diastolic values?

void loop(){

    // Information from the readBpm function will be saved to our "body"
    // variable.
    body = bioHub.readBpm();
    Serial.print("Heartrate: ");
....................

edspark, 2023-09-21:
Unfortunately this product does not use the sensor that is capable of providing systolic or diastolic values; this uses MAX32664**A**, and you would want MAX32664**D**. Hope that's helpful.

Nimesh-Patel, 2023-09-21:
Thank you edspark,
Please is there any place I can purchase MAX32664D sensor and GitHub repo with example code? I appreciate your quick response.
Thank You,
Nimesh

Closed 2023-09-21.

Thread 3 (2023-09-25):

To Measure BPT usingMAX32664D sensor GitHub repo with example code

Nimesh-Patel, 2023-09-25:
Please is there any place I can purchase MAX32664D sensor and GitHub repo with example code to measure BPT?

Thank You,
Nimesh

edspark, 2023-09-26:
Here is the manufacturer of the part, they're likely to have development boards based around their sensors:
https://www.analog.com/en/index.html

Closed 2023-09-26.

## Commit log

2019-02-05 Adds parts from temp lib to check parts.
    [SparkFun_Pulse_Oximeter_Heart-Rate_Sensor.brd, SparkFun_Pulse_Oximeter_Heart-Rate_Sensor.sch]
2019-02-05 Adds a few parts (end of day merge)
    [SparkFun_Pulse_Oximeter_Heart-Rate_Sensor.brd, SparkFun_Pulse_Oximeter_Heart-Rate_Sensor.sch]
2019-02-06 Adds parts to DC-DC converter
    [SparkFun_Pulse_Oximeter_Heart-Rate_Sensor.brd, SparkFun_Pulse_Oximeter_Heart-Rate_Sensor.sch]
2019-02-07 Many traces and parts have been added, too many to list.
    [SparkFun_Pulse_Oximeter_Heart-Rate_Sensor.brd, SparkFun_Pulse_Oximeter_Heart-Rate_Sensor.sch]
2019-02-08 Adds slik, trace work complete, ground vias added throughout design, schematic organized with lables
    [SparkFun_Pulse_Oximeter_Heart-Rate_Sensor.brd, SparkFun_Pulse_Oximeter_Heart-Rate_Sensor.sch]
2019-02-11 Moves silk labels around
    [SparkFun_Pulse_Oximeter_Heart-Rate_Sensor.brd, SparkFun_Pulse_Oximeter_Heart-Rate_Sensor.sch]
2019-02-11 Pushes temp lib to SparkFun Eagle Libraries and replaces parts in design with those parts
    [SparkFun_Pulse_Oximeter_Heart-Rate_Sensor.brd, SparkFun_Pulse_Oximeter_Heart-Rate_Sensor.sch]
2019-02-14 Fixes slik labels on bottom, adjusts traces on Oscillator and reset line, changes ground vias to 10 mil
    [SparkFun_Pulse_Oximeter_Heart-Rate_Sensor.brd, SparkFun_Pulse_Oximeter_Heart-Rate_Sensor.sch]
2019-02-14 Adds dimensions and special ordering instructions, adds text to MAX30101 that lists voltage ranges and I2C addresses
    [SparkFun_Pulse_Oximeter_Heart-Rate_Sensor.brd, SparkFun_Pulse_Oximeter_Heart-Rate_Sensor.sch]
2019-02-15 Clarifies "Address" text underneath MAX32664 symbol in schematic by adding "I2C"
    [SparkFun_Pulse_Oximeter_Heart-Rate_Sensor.brd, SparkFun_Pulse_Oximeter_Heart-Rate_Sensor.sch]
2019-02-15 Adds Production Files
    [SparkFun_Pulse_Oximeter_Heart-Rate_Sensor-Panel.GBL, SparkFun_Pulse_Oximeter_Heart-Rate_Sensor-Panel.GBO, SparkFun_Pulse_Oximeter_Heart-Rate_Sensor-Panel.GBP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]
2019-03-06 Deletes production files that were affected by DRC when they were panelized (more changes in description)
    * Adds new production files
    * Updates footprint of the Bio Sensor with new silk to outline part and has a bigger polarity marker
    [Panel.brd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]
2019-08-05 Adds firmware to repo
    [SparkFun_Pulse_Oximeter_Heart-Rate_Sensor.brd]
2019-09-13 Update SparkFun_Pulse_Oximeter_Heart-Rate_Sensor.brd
    - Spelling Error =P
    - Turn on Measurements to show Board Dimensions
    [SparkFun_Pulse_Oximeter_Heart-Rate_Sensor.brd]
2023-03-22 Updates silk, updates bio sensor hub to slightly improved package, rolls version to v11
    * Updates schematic to include part numbers on all parts
    * Updates notes on parts
    * Updates package size on 0402 components to 0402-tight
    * Adds more vias
    * Adds more measures
    [SparkFun_Pulse_Oximeter_Heart-Rate_Sensor.brd, SparkFun_Pulse_Oximeter_Heart-Rate_Sensor.sch]
2023-03-22 Adds new panel
    [Panel.brd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]
2023-03-22 Changes note on finish to ENIG
    [SparkFun_Pulse_Oximeter_Heart-Rate_Sensor.brd]

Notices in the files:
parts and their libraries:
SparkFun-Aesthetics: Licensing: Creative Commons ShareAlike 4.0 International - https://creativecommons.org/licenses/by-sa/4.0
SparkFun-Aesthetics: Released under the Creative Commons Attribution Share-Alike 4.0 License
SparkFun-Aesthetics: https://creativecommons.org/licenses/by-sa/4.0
